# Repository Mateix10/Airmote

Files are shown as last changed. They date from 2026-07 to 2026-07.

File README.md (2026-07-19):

# Airmote

Control any IR device and monitor room temperature, pressure and humidity with Home Assistant.

# Zine

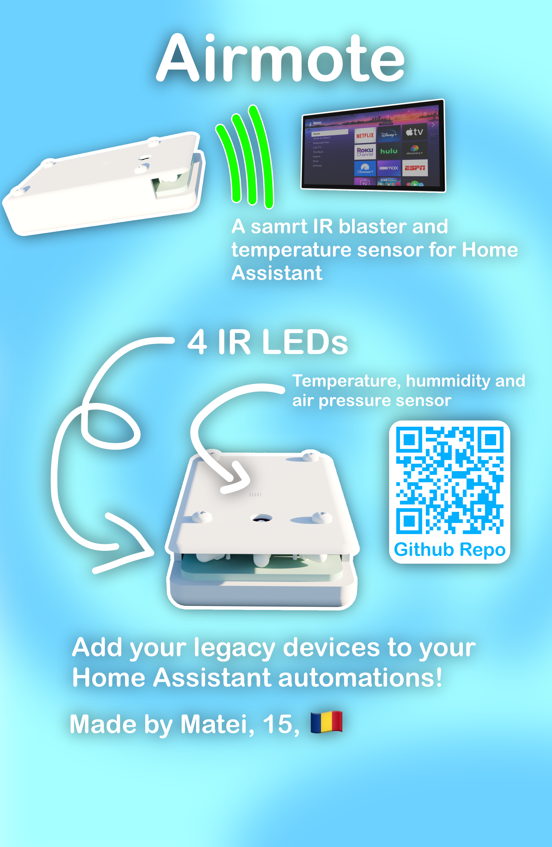
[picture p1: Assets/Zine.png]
Zine


# Why?

I always wanted to add my older devices that aren't compatible with Home Assistant to my automations. I want to turn my old stereo on when I start playing music, without having to reach for the half-broken remote.

# Firmware

For the firmware, use [ESPHome](https://esphome.io)

[Install guide](https://esphome.io/guides/getting_started_hassio/)

Code for the BME280 temperature sensor:

```yaml
sensor:
  - platform: bme280_i2c
    temperature:
      name: "BME280 Temperature"
    pressure:
      name: "BME280 Pressure"
    humidity:
      name: "BME280 Humidity"
```
... and for the IR:

```yaml
remote_transmitter:
  pin: GPIOXX
  carrier_duty_percent: 50%

climate:
  - platform: REPLACEME     # you need to replpace the platform to your AC. See esphome documentation for more
    name: "Living Room AC"
    sensor: room_temperature
    use_fahrenheit: false
```

Note: this is untested code.

# Schematic and PCB

The schematic and PCB are pretty simple, just connecting the LEDs to a 2n2222 transistor and accompanying resistors for protection.

The BME 280 sensor is connected trough I2C. It's connected that way becaouse it simplifies the PCB and the sensor doesn't need fast data.

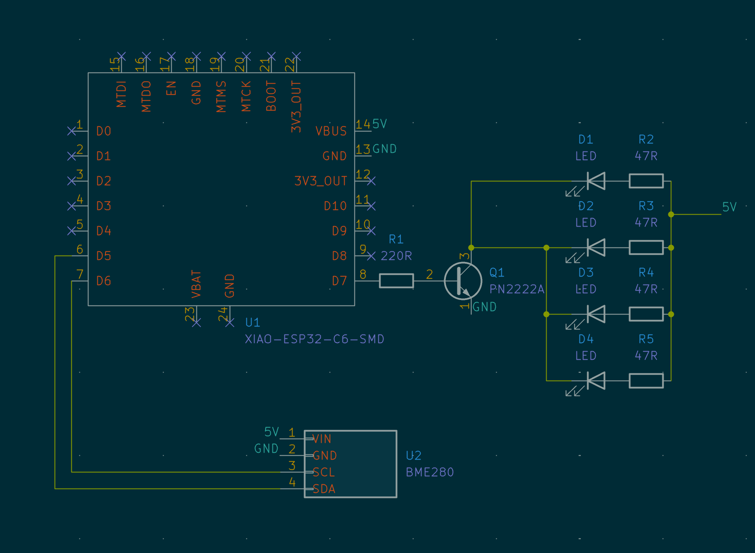
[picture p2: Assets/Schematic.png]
Schematic


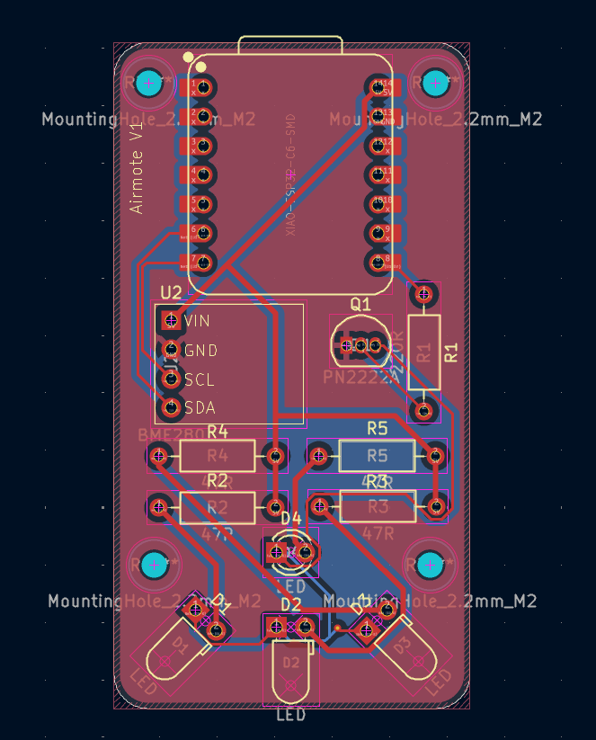
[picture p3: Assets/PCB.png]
PCB


# Case

I went for a industrial design as this device is intended to be hidden away on a high surface, away from sight. The bottom and top of the case are held by m2 screws along side bolts and heat inserts.

Designed in Fusion 360.
Files are available in 3D/Airmote.f3z

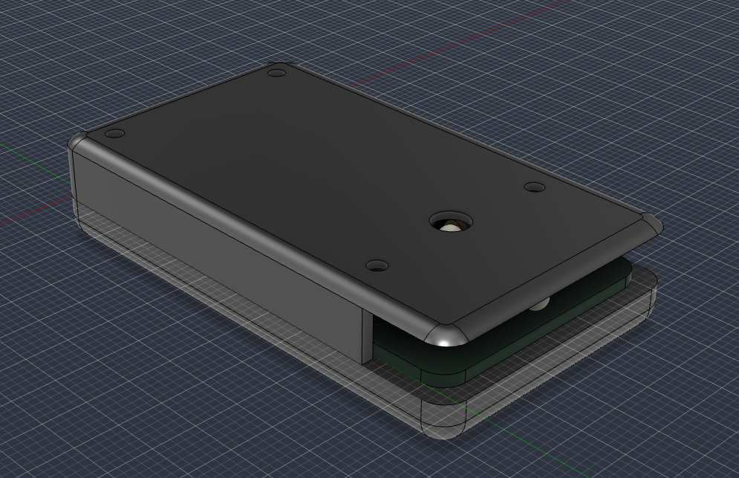
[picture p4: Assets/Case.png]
CAD


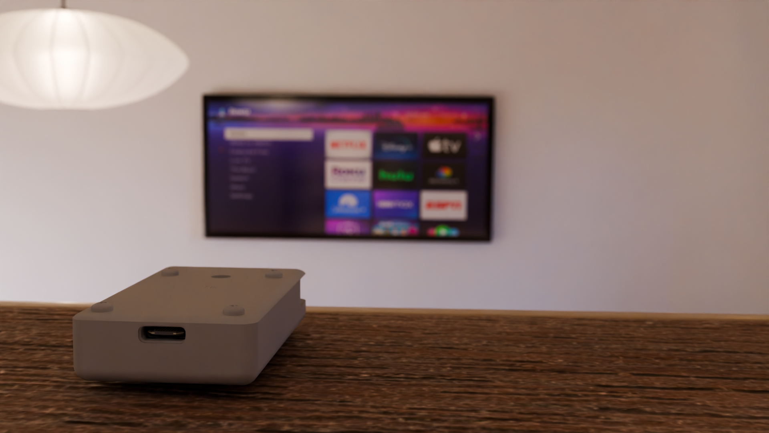
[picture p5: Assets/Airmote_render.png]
Render


# BOM

|Item|Count|Price|Link|
|--|--|--|--|
|Seeed Studio XIAO ESP32-C6|1|$5.20|[Seeed Studio](https://www.seeedstudio.com/Seeed-Studio-XIAO-ESP32C6-p-5884.html)|
|**3mm 940nm IR LED***|4|$1.47/lot|[Aliexpress](https://www.aliexpress.com/item/1005002345587711.html)|
|**2N2222 transistor***|1|$3.75/lot|[Aliexpress](https://www.aliexpress.com/item/1005010396511377.html)  (Select 2n2222 in the listing)|
|**220 Ohm resistor***|1|$0.63/lot|[Aliexpress](https://www.aliexpress.com/item/1005002489867848.html) (Select 220R in the listing)|
|**47 Ohm resistor***|4|$0.63/lot|[Aliexpress](https://www.aliexpress.com/item/1005002489867848.html) (Select 47R in the listing)|
|BME280 sensor breakout board|1|$4.00|[Aliexpress](https://www.aliexpress.com/item/1005012601108975.html) (Select 5V or else it won't fit)|
|**Heat brass inserts***|4|$7.09/lot|[Aliexpress](https://www.aliexpress.com/item/1005006798286851.html) (Select M2(OD3mm) and 2mm length)|
|**M2 Screws***|4|$3.85/lot|[Aliexpress](https://www.aliexpress.com/item/4000038065691.html) (Select M2 10mm in the listing)|
|PCB|1|$2|[JLCPCB](https://jlcpcb.com)
|Shipping|-|$69.39|-|
|**Total**|-|$92.81|-| 

***ONLY** buy the listing of **bolded** items ONCE. Those are sold as a lot and you will be getting 50/100pcs per listing bought.

# Credits

[Hackclub Fallout](https://fallout.hackclub.com) - Founding

[Kicad](https://kicad.org) - Schematic and PCB design

[ESPHome](https://esphome.io) - Firmware

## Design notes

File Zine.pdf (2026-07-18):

# Airmote

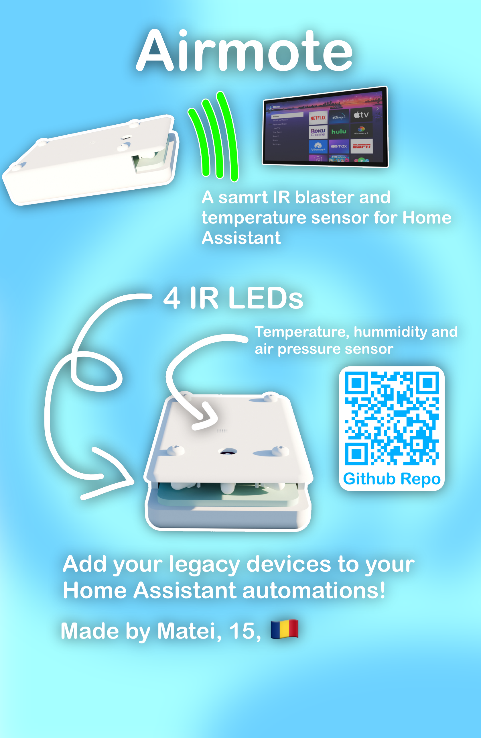
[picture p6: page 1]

## 4 IR LEDs

Add your legacy devices to your Home Assistant automations!

A samrt IR blaster and
temperature sensor for Home Assistant

Temperature, hummidity and air pressure sensor

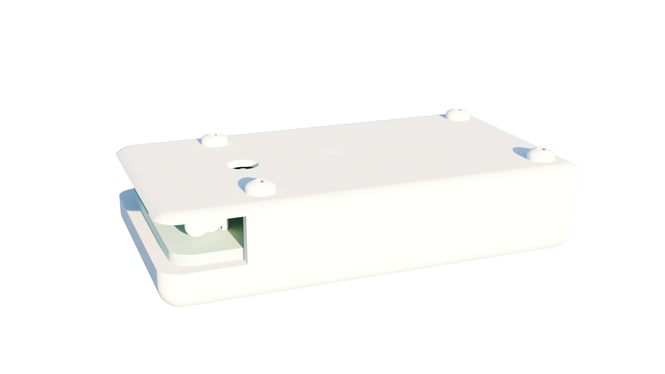
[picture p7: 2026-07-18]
Assets/Device_Transparent.png

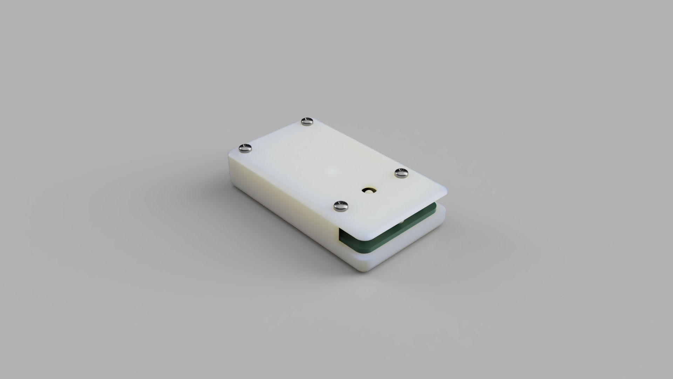
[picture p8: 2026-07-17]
Assets/CAD_RENDER.PNG

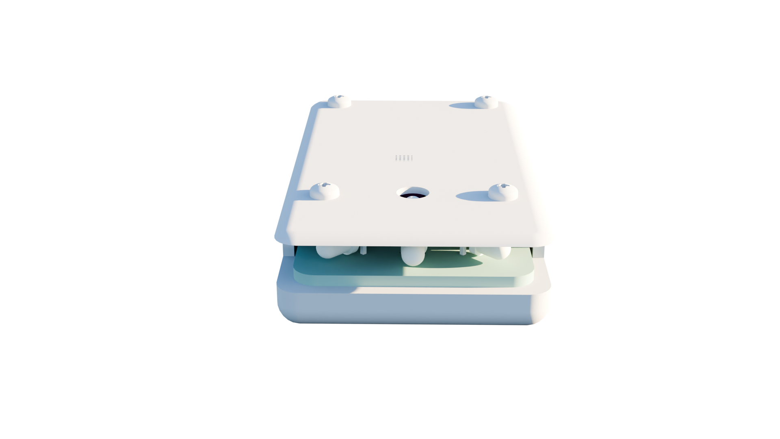
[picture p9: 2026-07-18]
Assets/Device_Transparent_closeup.png

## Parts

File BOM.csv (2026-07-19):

Item | Count | Price | Link
Seeed Studio XIAO ESP32-C6 | 1 | $5.20 | https://www.seeedstudio.com/Seeed-Studio-XIAO-ESP32C6-p-5884.html
3mm 940nm IR LED | 4 | $1.47/lot | https://www.aliexpress.com/item/1005002345587711.html
2N2222 transistor | 1 | $3.75/lot | https://www.aliexpress.com/item/1005010396511377.html
220 Ohm resistor | 1 | $0.63/lot | https://www.aliexpress.com/item/1005002489867848.html
47 Ohm resistor | 4 | $0.63/lot | https://www.aliexpress.com/item/1005002489867848.html
BME280 sensor breakout board | 1 | $4.00 | https://www.aliexpress.com/item/1005012601108975.html
Heat brass inserts | 4 | $7.09/lot | https://www.aliexpress.com/item/1005006798286851.html
M2 Screws | 4 | $3.85/lot | https://www.aliexpress.com/item/4000038065691.html
PCB | 1 | $2.00 | https://www.jlcpcb.com/
Shipping |  | $63.05
Total |  | $89.81

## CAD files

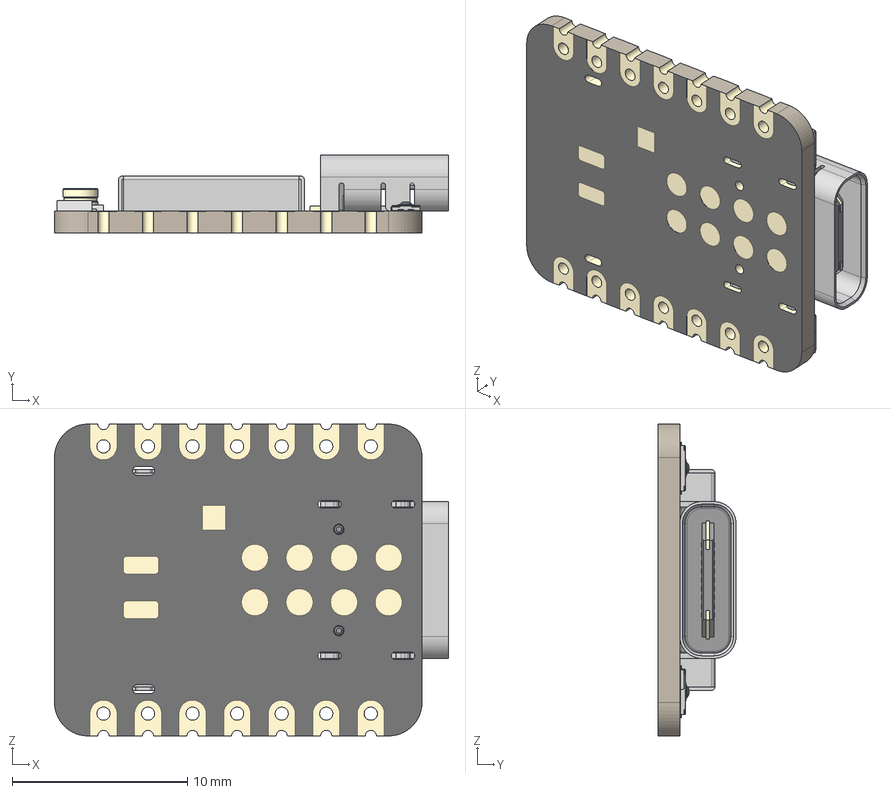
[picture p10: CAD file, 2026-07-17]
3D/3d_Models_for_parts/Seeed Studio XIAO ESP32-C6.step
22.5 x 4.46 x 17.8 mm
BOSS-EXTRUDE14_8_
BOSS-EXTRUDE7_4_
BOSS-EXTRUDE7_3_
BOSS-EXTRUDE14_4_
BOSS-EXTRUDE14_2_
BOSS-EXTRUDE14_11_
BOSS-EXTRUDE7_7_
BOSS-EXTRUDE14_9_
BOSS-EXTRUDE14_3_
BOSS-EXTRUDE14_7_
MIRROR2
BOSS-EXTRUDE14_5_
BOSS-EXTRUDE14_12_
BOSS-EXTRUDE7_8_
BOSS-EXTRUDE7_1_
BOSS-EXTRUDE14_10_
BOSS-EXTRUDE7_9_
BOSS-EXTRUDE14_6_
BOSS-EXTRUDE14_1_
BOSS-EXTRUDE7_6_
BOSS-EXTRUDE7_2_
CUT-EXTRUDE5
BOSS-EXTRUDE7_5_
U.FL Connector v1
Shield
SKTAAAE010 x 2
KH5220-A36 (Ceramic Antenna) v2

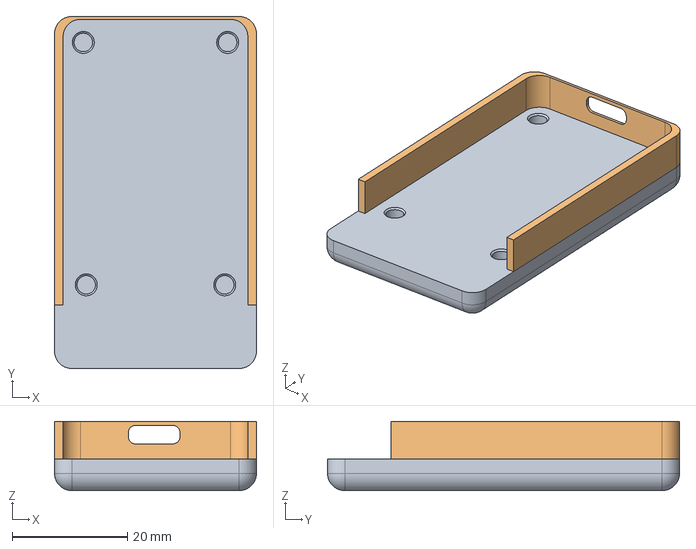
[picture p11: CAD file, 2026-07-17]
3D/Case_Bottom.step
35.0 x 61.0 x 12.0 mm

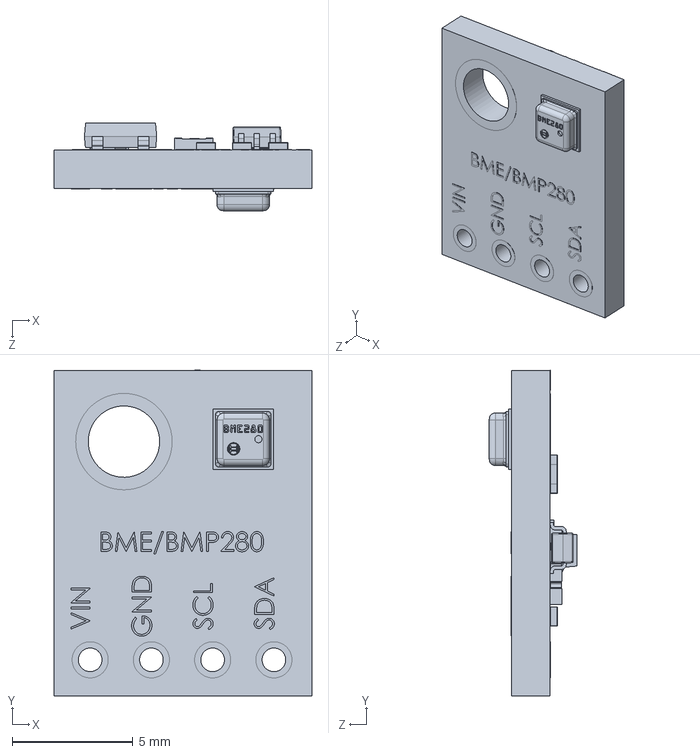
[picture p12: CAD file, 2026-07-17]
3D/3d_Models_for_parts/GY-BME280.SLDPRT
10.7 x 13.5 x 3.63 mm

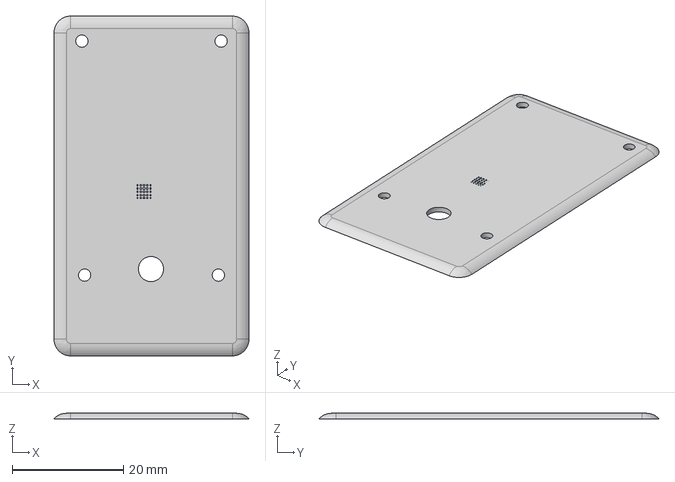
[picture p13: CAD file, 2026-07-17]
3D/Case_Top.step
35.0 x 61.0 x 1.00 mm

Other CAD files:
3D/Case_Bottom_3dprint.stl
3D/Case_Top_3dprint.stl
3D/Airmote.f3z

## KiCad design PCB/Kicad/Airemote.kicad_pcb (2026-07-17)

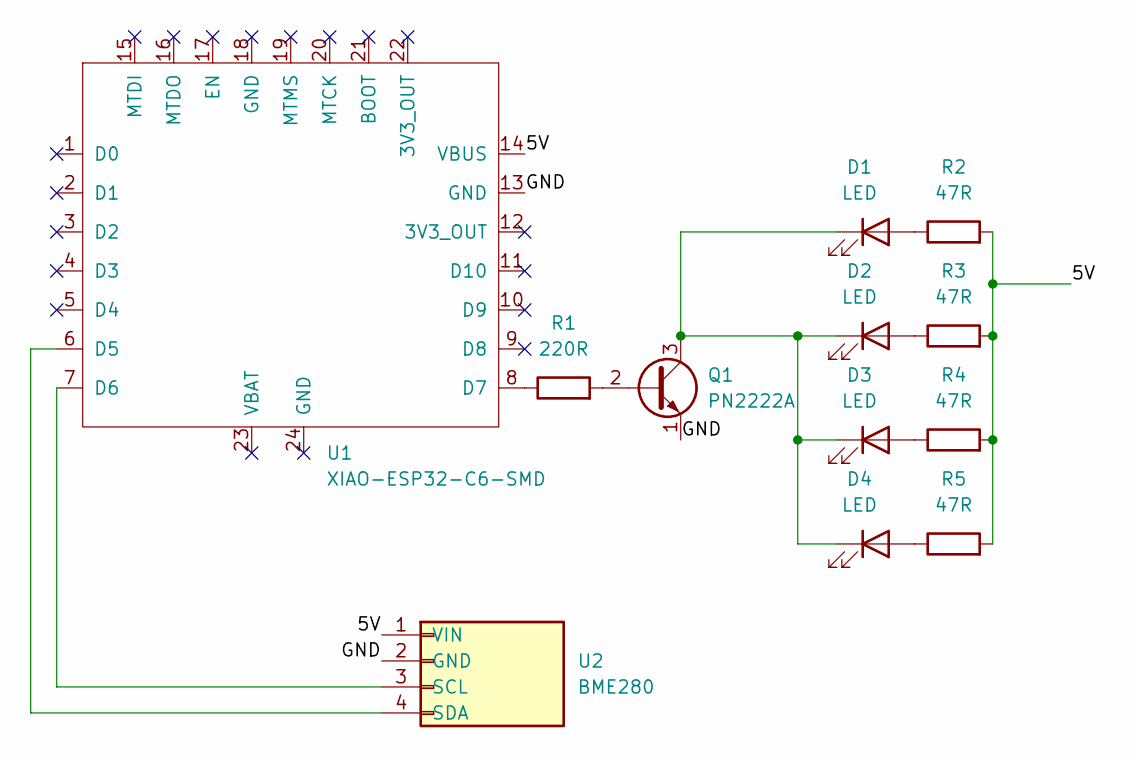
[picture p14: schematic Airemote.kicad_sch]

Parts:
D1, D2, D3: LED; LED_D3.0mm_Horizontal_O1.27mm_Z2.0mm_Clear
D4: LED; LED_D3.0mm_Clear
Q1: PN2222A; TO-92_Inline
R1: 220R; R_Axial_DIN0207_L6.3mm_D2.5mm_P10.16mm_Horizontal
R2, R3, R4, R5: 47R; R_Axial_DIN0207_L6.3mm_D2.5mm_P10.16mm_Horizontal
U1: XIAO-ESP32-C6-SMD; XIAO-ESP32-C6-DIP
U2: BME280; BME280_BreakOut

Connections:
/5V: R2.2, R3.2, R4.2, R5.2, U1.14 (VBUS), U2.1 (VIN)
/GND: Q1.1 (E), U1.13 (GND), U2.2 (GND)
unnamed: D1.2 (A), R2.1
unnamed: D1.1 (K), D2.1 (K), D3.1 (K), D4.1 (K), Q1.3 (C)
unnamed: D2.2 (A), R3.1
unnamed: D3.2 (A), R4.1
unnamed: D4.2 (A), R5.1
unnamed: Q1.2 (B), R1.2
unnamed: U1.6 (D5), U2.4 (SDA)
unnamed: U1.7 (D6), U2.3 (SCL)
unnamed: R1.1, U1.8 (D7)

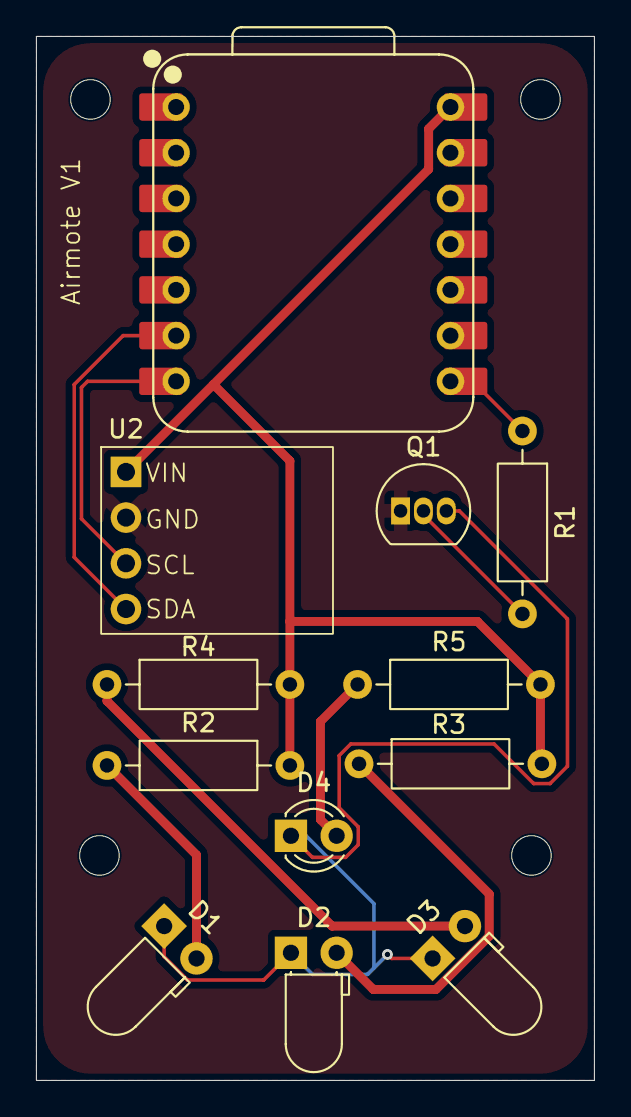
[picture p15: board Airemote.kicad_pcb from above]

Board: 2 copper layers, 31.0 x 58.0 mm, 12 parts (0 on the bottom side), 11 nets.

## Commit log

2026-07-17 Update files
    [Airemote.kicad_pcb, Case_Bottom.step, Case_Top.step]
2026-07-17 Add shipping to BOM
2026-07-17 Add BOM
    [BOM.csv]
2026-07-18 Add more info about frimware and PCB
2026-07-19 Add PCB to BOM
    [BOM.csv]
2026-07-19 Change folder structure
    [Airemote.kicad_pcb, Airemote.kicad_sch, GY-BME280.SLDPRT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]
